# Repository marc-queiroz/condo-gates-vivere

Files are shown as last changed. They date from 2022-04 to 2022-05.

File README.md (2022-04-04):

# condo-gates-vivere

# Working version
Python 3.6.4 (default, Jan 25 2018, 15:20:29) 
[GCC 7.2.1 20180116] on linux

## Running on raspberry pi rev0010

## How to run

python -m venv .

pip install -r requirements

python relay.py

## Project includes

Arduinos source code for gates simulator

Schematics for connections between **Raspberry Pi** and **Arduino**.

Observation: The Solid state relay should be replaced by a 5V relay with 3 pins VCC, GROUND and IN.

# Project on circuit-diagram.org

https://crcit.net/c/c7c45868cee941868d9534cdedbfd286

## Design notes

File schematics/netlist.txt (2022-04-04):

* Netlist created with www.circuit-diagram.org
* Gate control
D1 1 0
R2 2 1 1000
R3 4 3 1000
R4 6 5 1000
R5 4 7 100000
R6 6 7 100000
'phototransnpn2 col:8 emit:4 t=NPNPhototransistor2
D7 0 9
D8 10 9
'phototransnpn2 col:8 emit:6 t=NPNPhototransistor2
D9 11 10
R10 12 11 1000
R11 14 13 1000
'Solid State Relay Load2:14 Load1:15 NegativeCtrl:7 PositiveCtrl:16
D12 17 16
R13 18 17 1000
R14 20 19 1200
'transnpn col:16 base:7 emit:20 t=NPN
R15 21 13 1000
'Solid State Relay Load2:21 Load1:15 NegativeCtrl:7 PositiveCtrl:22
D16 23 22
R17 18 23 1000
R18 25 24 1200
'transnpn col:22 base:7 emit:25 t=NPN
R19 27 26 1000
R20 29 28 1000
R21 27 30 100000
R22 29 30 100000
'phototransnpn2 emit:27 col:8 t=NPNPhototransistor2
D23 31 32
D24 33 34
'phototransnpn2 emit:29 col:8 t=NPNPhototransistor2
'pushswitch b:35 a:32 t=Push closed=False
'pushswitch b:35 a:34 t=Push closed=False
R25 36 31 2000
R26 36 33 1000
V27 36 35 12
'microcontroller #87:12 #88:2 #90:9 #78:14 #77:21 #5:13 #4:15 #6:35 #7:36 header=Arduino Mega 2560 p0= p1=IOREF p2=RST p3=3V3 p4=5V p5=GND p6=GND p7=VIN p8= p9=A0 p10=A1 p11=A2 p12=A3 p13=A4 p14=A5 p15=A6 p16=A7 p17=A8 p18=A9 p19=A10 p20=A11 p21=A12 p22=A13 p23=A14 p24=A15 p25=GND p26=GND p27= p28=D53 p29=D52 p30=D51 p31=D50 p32=D49 p33=D48 p34=D47 p35=D46 p36=D45 p37=D44 p38=D43 p39=D42 p40=D41 p41=D40 p42=D39 p43=D38 p44=D37 p45=D36 p46=D35 p47=D34 p48=D33 p49=D32 p50=D31 p51=D30 p52=D29 p53=D28 p54=D27 p55=D26 p56=D25 p57=D24 p58=D23 p59=D22 p60= p61=5V p62=5V p63= p64=SCL D21 p65=SDA D20 p66=RX1 D19 p67=TX1 D18 p68=RX2 D17 p69=TX2 D16 p70=RX3 D15 p71=TX3 D14 p72= p73= p74= p75=RX0 D0 p76=TX0 D1 p77=D2 p78=D3 p79=D4 p80=D5 p81=D6 p82=D7 p83=D8 p84=D9 p85=D10 p86=D11 p87=D12 p88=D13 p89= p90=GND p91=AREF p92=SCL p93=SDA p94= p95= p96= p97= p98= p99=
'Raspberry Pi A+ / B+, 2 and Zero GPIO #14:3 #17:5 #38:19 #22:7 #20:18 #15:24 #37:28 #18:26 #36:30 #0:8

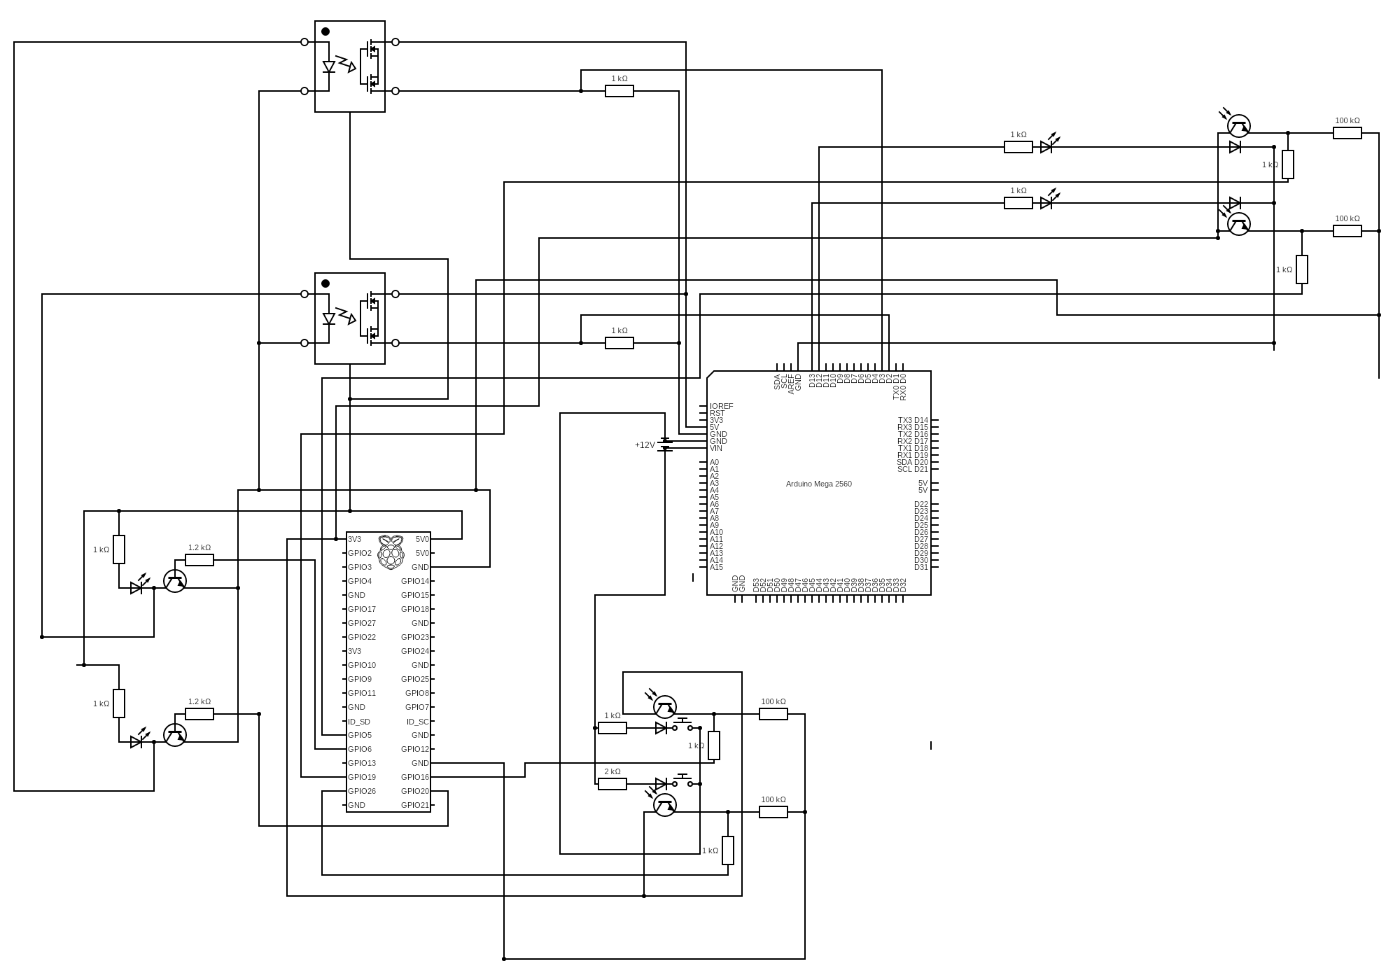
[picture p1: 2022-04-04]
schematics/circuit.png

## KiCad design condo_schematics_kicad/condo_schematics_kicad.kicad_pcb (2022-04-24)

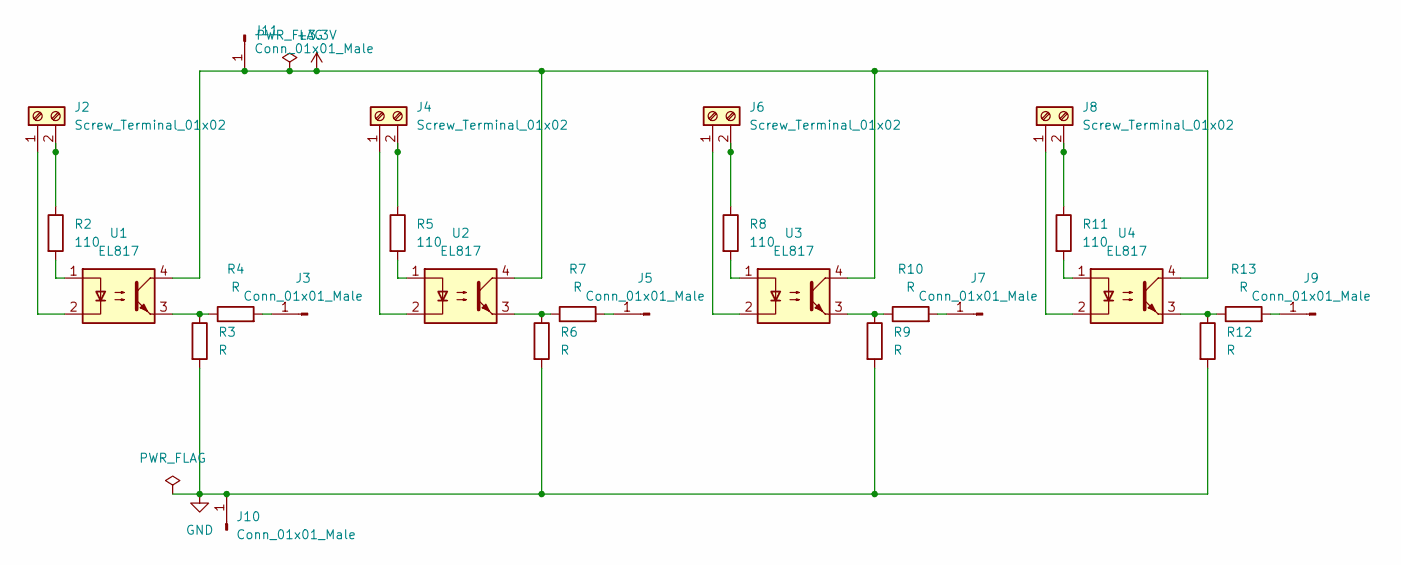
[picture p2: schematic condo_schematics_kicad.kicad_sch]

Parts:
J2, J4, J6, J8: Screw_Terminal_01x02; TerminalBlock_Altech_AK300-2_P5.00mm
J3, J5, J7, J9, J10, J11: Conn_01x01_Male; PinHeader_1x01_P2.54mm_Vertical
R2, R5, R8, R11: 110; R_Axial_DIN0207_L6.3mm_D2.5mm_P7.62mm_Horizontal
R3, R4, R6, R7, R9, R10, R12, R13: R; R_Axial_DIN0207_L6.3mm_D2.5mm_P7.62mm_Horizontal
U1, U2, U3, U4: EL817; DIP-4_W7.62mm

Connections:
+3V3: J11.1, U1.4, U2.4, U3.4, U4.4
GND: J10.1, R3.2, R6.2, R9.2, R12.2
unnamed: J2.1, U1.2
unnamed: J2.2, R2.1
unnamed: J3.1, R4.2
unnamed: J4.1, U2.2
unnamed: J4.2, R5.1
unnamed: J5.1, R7.2
unnamed: J6.1, U3.2
unnamed: J6.2, R8.1
unnamed: J7.1, R10.2
unnamed: J8.1, U4.2
unnamed: J8.2, R11.1
unnamed: J9.1, R13.2
unnamed: R2.2, U1.1
unnamed: R3.1, R4.1, U1.3
unnamed: R5.2, U2.1
unnamed: R6.1, R7.1, U2.3
unnamed: R8.2, U3.1
unnamed: R9.1, R10.1, U3.3
unnamed: R11.2, U4.1
unnamed: R12.1, R13.1, U4.3

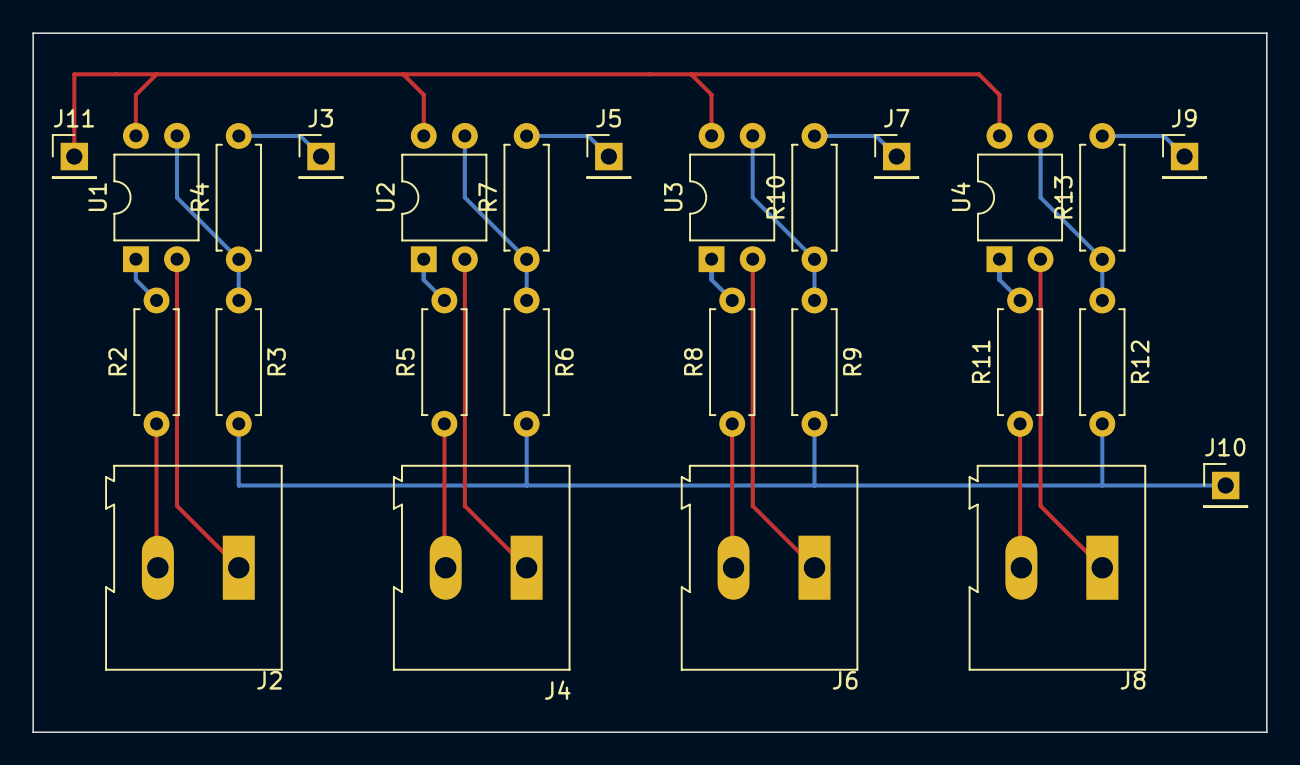
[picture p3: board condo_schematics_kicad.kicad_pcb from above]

Board: 2 copper layers, 76.2 x 43.2 mm, 26 parts (0 on the bottom side), 22 nets.

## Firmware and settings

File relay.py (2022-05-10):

import RPi.GPIO as GPIO
import time
from threading import Timer, Lock
from datetime import datetime

gpio23 = 23 # relay gate0
gpio17 = 17 # relay gate1
gpio26 = 26 # remote control gate0
gpio16 = 16 # remote control gate1
gpio05 = 5 # sensor of gate0
gpio19 = 19 # sensor of gate1
gate_counter = 0

# GPIO setup
GPIO.setmode(GPIO.BCM)
GPIO.setup(gpio26, GPIO.IN)
GPIO.setup(gpio16, GPIO.IN)
GPIO.setup(gpio05, GPIO.IN)
GPIO.setup(gpio19, GPIO.IN)
GPIO.setup(gpio23, GPIO.OUT, initial=GPIO.LOW)
GPIO.setup(gpio17, GPIO.OUT, initial=GPIO.LOW)

lock = Lock()

def motor_on(pin):
    print('motor_on', pin)
    GPIO.output(pin, GPIO.HIGH) # Turn motor on

def motor_off(pin):
    print('motor_off', pin)
    GPIO.output(pin, GPIO.LOW) # Turn motor off

def gate0(test):
    lock.acquire()
    colision_gate1 = GPIO.input(gpio16)
    if GPIO.input(gpio05) or colision_gate1 or GPIO.input(gpio17):
        lock.release()
        if colision_gate1:
            print('Gate0 reports colision with gate1 ', datetime.now())
        return
    motor_on(gpio23)
    r = Timer(1.0, motor_off, (gpio23,))
    r.start()
    lock.release()

def gate1(test):
    lock.acquire()
    colision_gate0 = GPIO.input(gpio26)
    if GPIO.input(gpio19) or colision_gate0 or GPIO.input(gpio23):
        lock.release()
        if colision_gate0:
            print('Gate1 reports colision with gate0 ', datetime.now())
        return
    motor_on(gpio17)
    r = Timer(1.0, motor_off, (gpio17,))
    r.start()
    lock.release()

GPIO.add_event_detect(gpio26, GPIO.RISING, callback=gate0, bouncetime=1300)
GPIO.add_event_detect(gpio16, GPIO.RISING, callback=gate1, bouncetime=1300)

if __name__ == '__main__':
    print('System ready!')
    try:
        while True:
            time.sleep(0.1)
    except KeyboardInterrupt:
        GPIO.cleanup()

# if __name__ == '__main__':
#     try:
#         # motor_on(gpio23)
#         # motor_on(gpio17)
#         time.sleep(1)
#         # motor_off(gpio23)
#         # motor_off(gpio17)
#         time.sleep(1)
#         GPIO.cleanup()
#     except KeyboardInterrupt:
#         GPIO.cleanup()

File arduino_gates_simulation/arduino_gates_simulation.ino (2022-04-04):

/*
  Button

  Turns on and off a light emitting diode(LED) connected to digital pin 13,
  when pressing a pushbutton attached to pin 2.

  The circuit:
  - LED attached from pin 13 to ground through 220 ohm resistor
  - pushbutton attached to pin 2 from +5V
  - 10K resistor attached to pin 2 from ground

  - Note: on most Arduinos there is already an LED on the board
    attached to pin 13.

  created 2005
  by DojoDave <http://www.0j0.org>
  modified 30 Aug 2011
  by Tom Igoe

  This example code is in the public domain.

  https://www.arduino.cc/en/Tutorial/BuiltInExamples/Button
*/

// constants won't change. They're used here to set pin numbers:
const int buttonPin0 = 2;     // the number of the pushbutton pin
const int buttonPin1 = 3;
const int ledPin0 = 13;      // the number of the LED pin
const int ledPin1 = 12;
const long interval = 12000;
unsigned long previousMillis0 = 0;
unsigned long previousMillis1 = 0;

// variables will change:
int button0State = 0;         // variable for reading the pushbutton status
int button1State = 0;

void setup() {
  // initialize the LED pin as an output:
  pinMode(ledPin0, OUTPUT);
  pinMode(ledPin1, OUTPUT);
  // initialize the pushbutton pin as an input:
  pinMode(buttonPin0, INPUT);
  pinMode(buttonPin0, INPUT);
}

void loop() {
  // read the state of the pushbutton value:
  button0State = digitalRead(buttonPin0);
  button1State = digitalRead(buttonPin1);

  unsigned long currentMillis = millis();
  
  // check if the pushbutton is pressed. If it is, the buttonState is HIGH:
  if (button0State == HIGH) {
    // turn LED on:
    digitalWrite(ledPin0, HIGH);
    previousMillis0 = currentMillis;
  }

  if (button1State == HIGH) {
    // turn LED on:
    digitalWrite(ledPin1, HIGH);
    previousMillis1 = currentMillis;
  }

  if (currentMillis - previousMillis0 > interval) {
    // turn LED off:
    digitalWrite(ledPin0, LOW);
  }

  if (currentMillis - previousMillis1 > interval) {
    // turn LED off:
    digitalWrite(ledPin1, LOW);
  }
}

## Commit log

2022-04-04 Programming for raspberry PI to run two gates doors simultaneously
    - Radio input for 2 gates
    - Sensor for gates operation
    - Relay to action the gates
2022-04-04 Adding arduino mega 2560 - Gates simulator
    - Without a real gate input and output, this code was created to
    simulate to independent gates. The purpose of the all project is to
    prevent the activation of both gates, cause of accidents in the
    condominium.
    [arduino_gates_simulation.ino]
2022-04-04 Instructions for the project
    - Schematics for connects between Arduino and Raspberry Pi
2022-04-04 Adding URL to Circuit Diagram project
2022-04-04 Adding schematics
    CDDX file for circuit-diagram.org.
    Netlist, compatible with program SPICE see wikepedia.
    PNG and SVG circuit representation.
2022-04-17 Adding mutex to the code and changing the gpio pin
2022-04-22 Adding a initial circuit with schematics and pcb working
    [condo_schematics_kicad.kicad_pcb, condo_schematics_kicad.kicad_sch]
2022-04-24 Adding kicad schematics and PCB
    [condo_schematics_kicad.kicad_pcb, condo_schematics_kicad.kicad_sch]
2022-04-24 Cleaning test schematics and PCBs
    [condo_schematics_kicad.kicad_pcb, condo_schematics_kicad.kicad_sch]
2022-04-25 Adding new rules to avoid colision between the gates
    - If both gates are detected in same time, none will activate the gates.
    [relay.py]
2022-05-07 Fixing relay getting fired by neighboard pins
    - When a relay is fired the oder relay should not be ON.
    - In case of trying to fire the gate detect the other relay active should return
    [relay.py]
2022-05-10 Changing relay pins to avoid electrical noise
    [relay.py]
